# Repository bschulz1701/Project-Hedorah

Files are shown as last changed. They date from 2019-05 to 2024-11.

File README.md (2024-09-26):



# Project-Hedorah
A hardened CO2 sensing system designed for use in unusual environments 

>[!NOTE]
> Manufacture and assembly information is discussed in detail in [DFM_-_Hedorah-NDIR](https://github.com/GEMS-sensing/DFM_-_Hedorah-NDIR)

# Repo Roadmap
#### [Documents](Documents/)

General document and image storage for repo and README

#### [Hardware](Hardware/)

Current board files (Eagle), and other electrical design documents

#### [Mechanical](Mechanical/)

Mechanical design files and assembly documents

#### [Production](Production/)

Contains the various Gerber and pick and place files required to have the Printed Circuit Boards (PCBs) manufactured or populated 

#### [Software](Software/)

The software associated with the piece of hardware, this is usually diagnostic software used for verifying or investigating the hardware

<!-- #### [Testing](Testing/)

Scripts and results from the testing process and development process. Contains more detailed information about documented issues among other testing. --> 

## Overview
* **Type:** Sensor
* **Interfaces:** I<sup>2</sup>C
<!-- * **Release Version:** v1.0 - 2021/04/14  -->

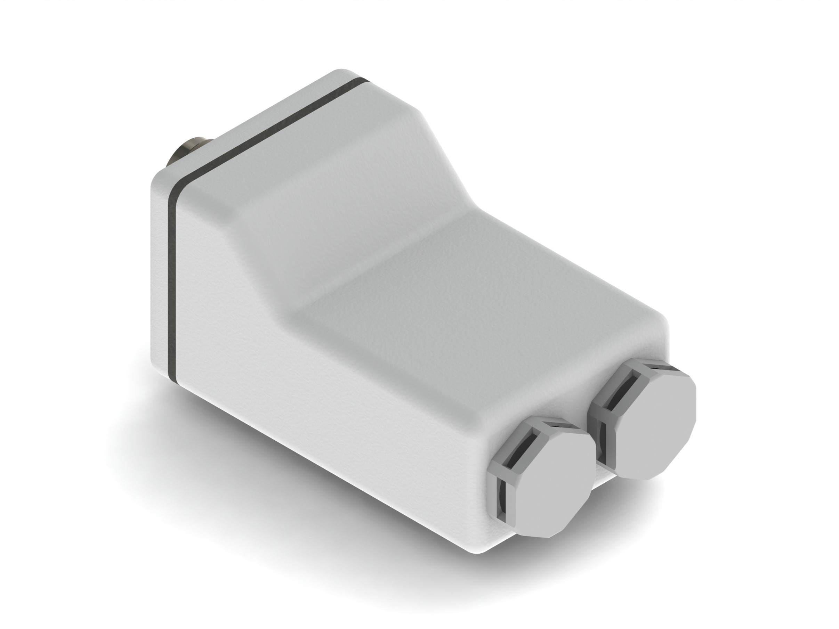
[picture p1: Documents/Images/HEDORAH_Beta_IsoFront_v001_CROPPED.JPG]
Hedroah Mrk 2 Enclosure Render, Isometric


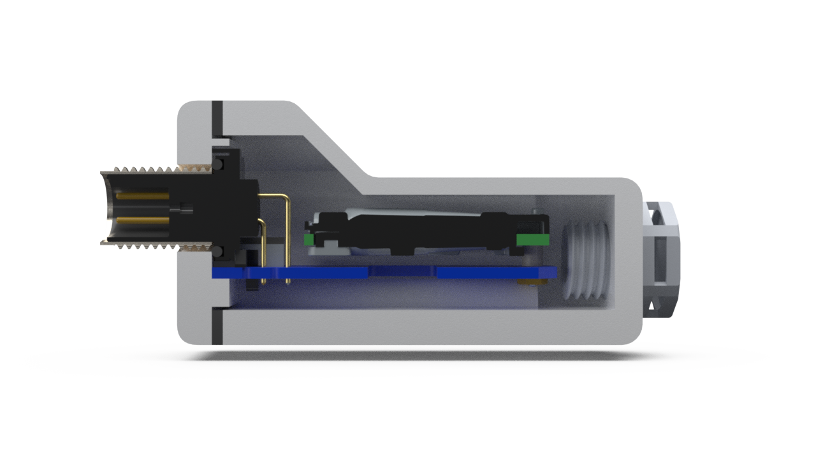
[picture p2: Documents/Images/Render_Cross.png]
Hedroah Mrk 2 Enclosure Render, Cross Section


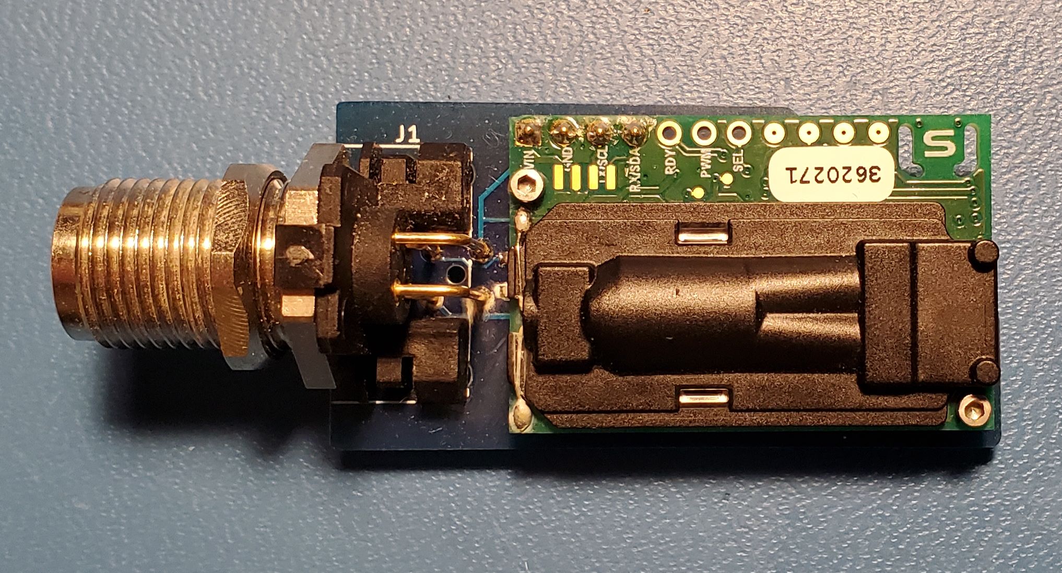
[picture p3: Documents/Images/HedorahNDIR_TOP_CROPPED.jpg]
Hedroah NDIR v1.0 - Top


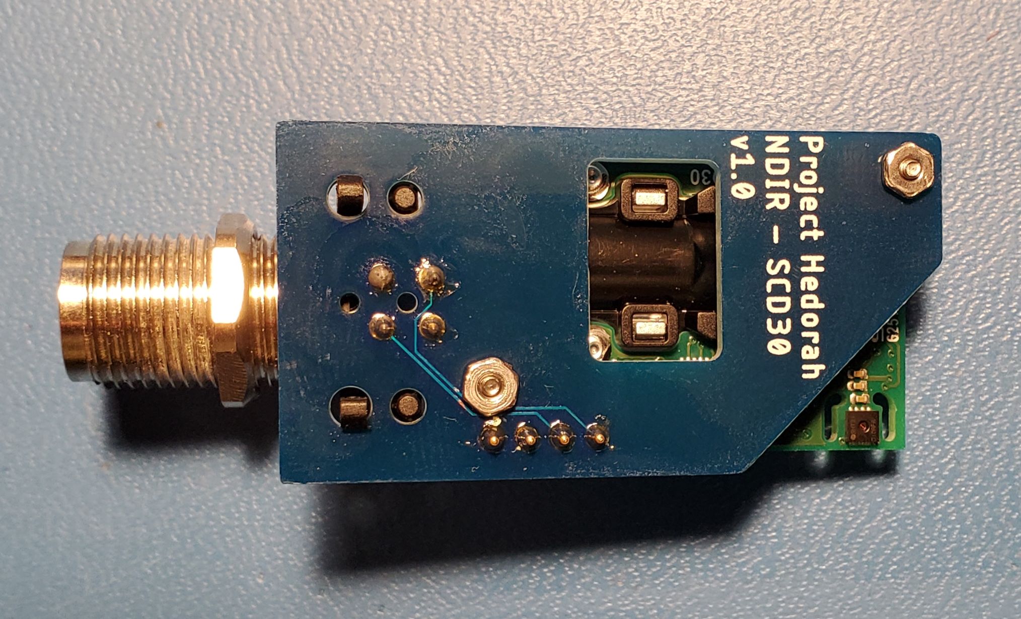
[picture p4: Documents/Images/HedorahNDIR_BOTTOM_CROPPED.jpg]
Hedroah NDIR v1.0 - Bottom


## Features
### On-Board
* Non-Dispersive InfraRed (NDIR) CO2 sensor - Sensirion SCD30
* IP68 rating (hardened sensor housing)

### Interface
* I<sup>2</sup>C data interface
* M12 circular connector 

<!-- ![Pinout](Documents/Images/Pinout.png) -->

<picture>
  <source media="(prefers-color-scheme: dark)" srcset="Documents/Images/Pinout_LIGHT.png">
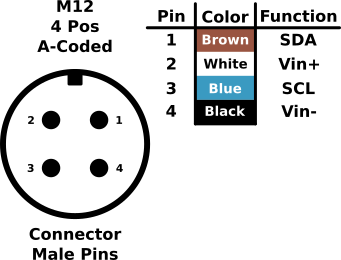
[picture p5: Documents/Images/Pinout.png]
Hedorah Connector Pinout
  
</picture>

## Specifications
#### Electrical
* **Input Voltage:** 3.3V
* **Sensor Current (Avg):** 19mA [^1]
* **Sensor Current (Max):** 75mA [^1]

[^1]: [SCD30 Datasheet](https://sensirion.com/media/documents/4EAF6AF8/61652C3C/Sensirion_CO2_Sensors_SCD30_Datasheet.pdf)

#### Sensor [^1]
**CO2**
* Range: 0 ~ 40,000 ppm CO2 
* Accuracy: &plusmn; 30 ppm + (3% Measured Value)
* Repeatability: &plusmn; 10 ppm

**Humidity**
* Range: 0 ~ 100%
* Accuracy: &plusmn; 3%
* Repeatability: 0.1%

**Temperature**
* Range: -40 ~ 70°C 
* Accuracy: &plusmn; (0.4°C + 0.023 x (Temperature [°C] - 25°C))
* Repeatability: &plusmn; 0.1°C

## Version History

**Mrk 0 - Prototype:** Breakout/development board for SGP30 eCO2 sensor

**Mrk 1 - eCO2:** Same components as Mrk 0, but arranged into a streamlined formfactor, compatable with [Haar](https://github.com/NorthernWidget-Skunkworks/Project-Haar) enclosure 

**Mrk 2 - NDIR:** Switched sensor to SCD30 NDIR sensor, moved away from Haar enclosure to custom enclosure

  * `v0.0` - Initial NDIR version, breakout only

  * `v1.0` - Added reverse polarity protection and I2C pullups

**Mrk 3 - Dual (BETA):** Dual sensor version with low and high range sensor

## Jumper Settings 

**Configuration Jumpers** [^2]
| Jumper | Purpose | Open | Closed | Default | 
| --- | --- | --- | --- | ----- |
| `JP1` | Bypass reverse polarity protection | protection enabled | protection disabled | Open |  

[^2]: Mrk 2 only

## Known Issues/Errata

#### Vent Thread Tolerance 

**Issue:** In some cases the tolerance of the thread manufacture on the [housing body](Mechanical/HEDORAH-001_-_BetaBody/HEDORAH-001_-_BetaBody_v001.stl) can be too tight. This can be seen clearly if applying the specified torque to the vents does not screw them fully down (O-Rings making contact with the housing body). 

**Workaround:** If the issue is minor, it can be corrected by applying some plastic compatible [silicone lubricant](https://www.mcmaster.com/3025K11/) to the threads of the vent before installing - take care to only apply this to the threads and not to contaminate the vent membrane. If this is not sufficient, threads can be repaired by running an [M12x1.5mm](https://www.mcmaster.com/26015A612/) hand-tap through the holes to ensure they meet specifications.

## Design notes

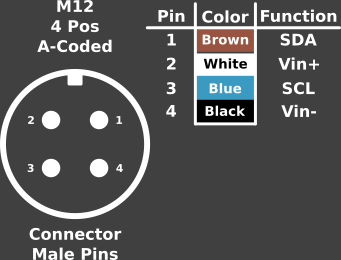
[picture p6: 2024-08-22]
Documents/Images/Pinout_LIGHT.png

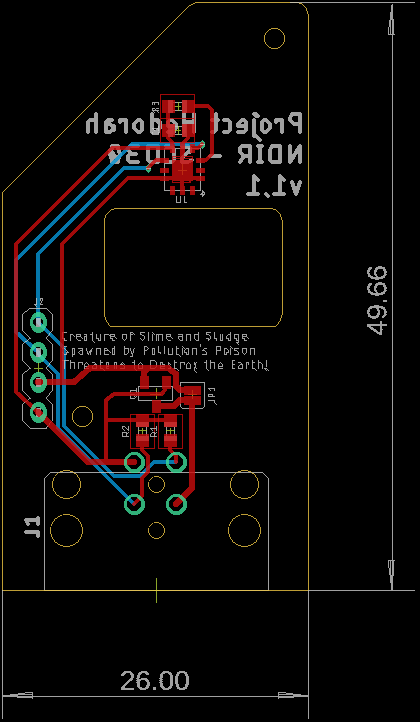
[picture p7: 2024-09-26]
Hardware/Mrk 2 - NDIR/BoardDimensions.png

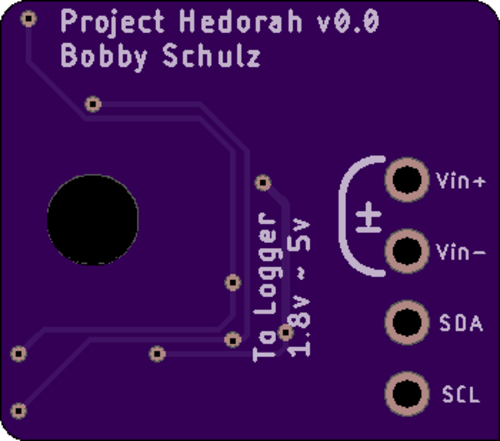
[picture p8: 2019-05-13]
Images/Bottom_Render.png

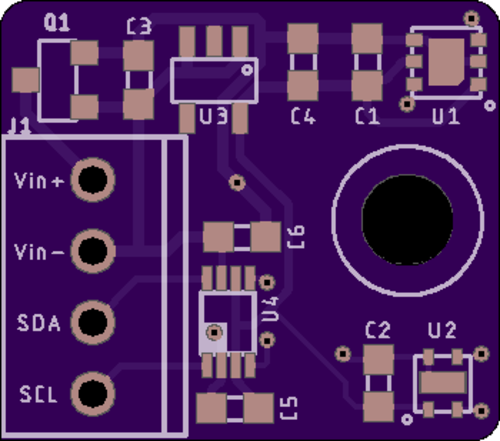
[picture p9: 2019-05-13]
Images/Top_Render.png

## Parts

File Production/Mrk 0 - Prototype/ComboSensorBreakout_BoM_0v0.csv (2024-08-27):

Qty | Value | Device | Package | Parts | Description | DIGIKEY | DISP | MF | MOUSER | MPN | VALUE
1 |  | MOUNTING_HOLE4_NP | 4_40 | H1 | Genaric Mechanical Mounting Hole | DNP |  | N/A |  | DNP
4 | 0.1uF | C-EU0.1UFC0603 | C0603 | C1, C2, C5, C6 | CAPACITOR, European symbol | 490-6051-1-ND |  | Murata |  | GCM188R71E104KA57D
2 | 1uF | C-EU1UFC0603 | C0603 | C3, C4 | CAPACITOR, European symbol | 490-10479-1-ND |  | Murata |  | GRM188R61C105KA12D
1 | CONN_42.54_SCREW | CONN_42.54_SCREW | 1X04_SCREW | J1 | Genaric 4 terminal header | ED10563-ND |  | On Shore |  | OSTVN04A150
1 | DMG3404 | MOSFET-NCH-DMG3404L | SOT23-3 | Q1 | N-channel MOSFETs | DMG3404L-7DICT-ND |  | Diodes Incorporated |  | DMG3404L-7 | DMG3404
1 | SHTC3DFN | SHTC3DFN | DFN_4_2X2 | U2 | SHTCx - Digital Humidity and Temperature Sensor | 1649-1100-1-ND | SHTC3 | Sensirion |  | SHTC3
1 | SPG30 | SPG30 | DFN_6_2.5X2.5 | U1 | SGP30 - Multi-pixel Gas Sensor (TVOC, CO2EQ) | 1649-1084-1-ND |  | Sensirion |  | SGP30-2.5K
1 | TPS7A0518DBV | TPS7A0518DBV | SOT23-5 | U3 | TPS7A05* - Ultra Low Power Low Dropout Linear Regulator | 296-50251-1-ND |  | TI | 595-TPS7A0518PDBVR | TPS7A0518PDBVR
1 | TXS0102DCU | TXS0102DCU | DCU_(R-PDSO-G8) | U4 | TXS0102 - 2 Channel Bidirectional Voltage Level Translator | 296-21931-1-ND |  | TI |  | TXS0102DCUR

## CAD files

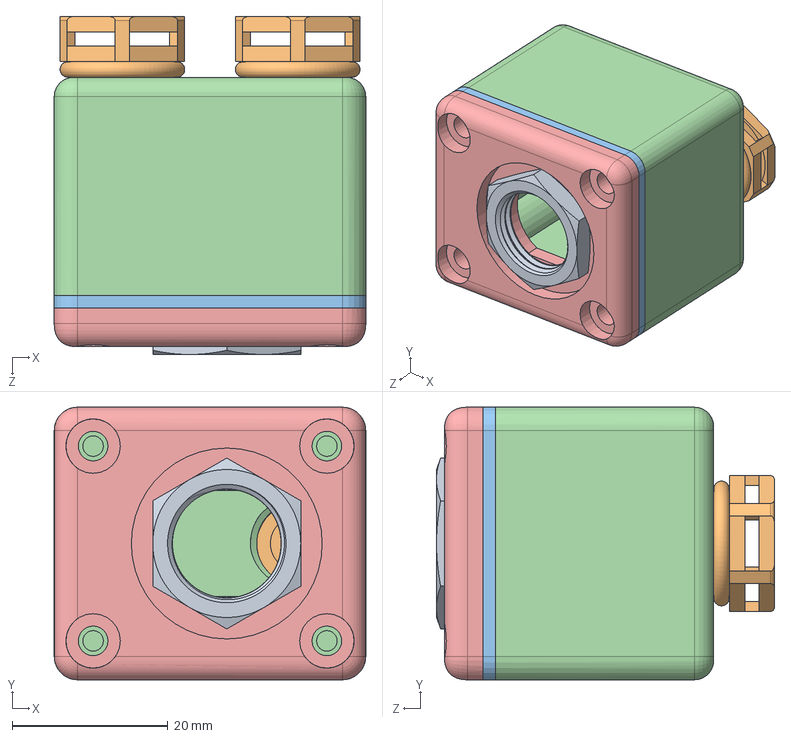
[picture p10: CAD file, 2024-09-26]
Mechanical/Mrk 3 Body Assembly/VertFull.SLDASM
40.0 x 35.0 x 43.4 mm
HEDORAH-004_-_VertLid_v000
HEDORAH-005_-_VertBody-v000
HEDORAH-003_-_BetaGasket_v001
M12_Vent_wMembrane x 2
7513K142_PG-9 304 Stainless Steel Locknut for Metal Medium- and Thick-Wall Steel Conduit

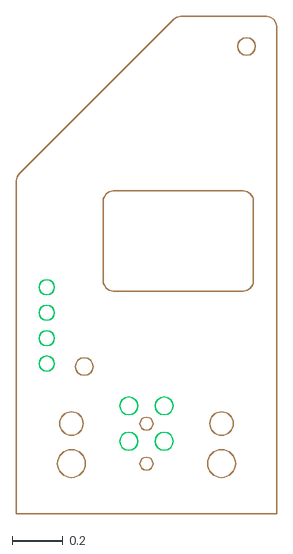
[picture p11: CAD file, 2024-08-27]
Hardware/Mrk 2 - NDIR/NDIR_SensorInterface_AllHoles.dxf
1.02 x 1.96

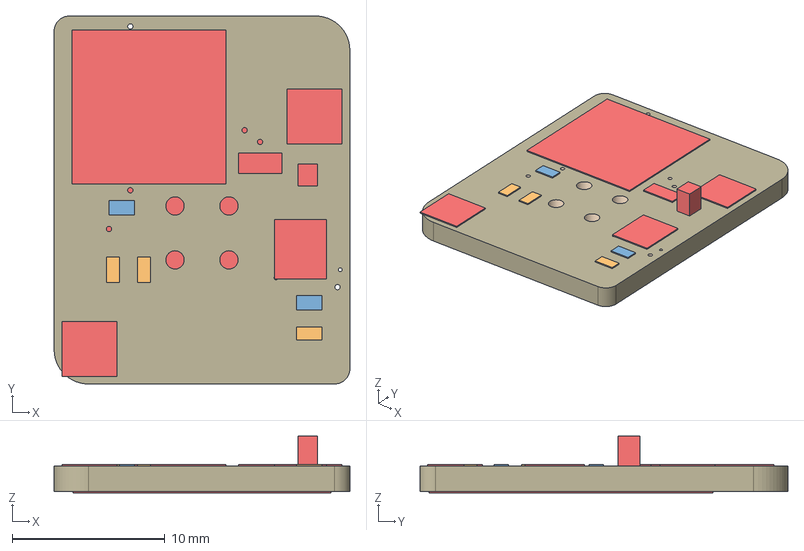
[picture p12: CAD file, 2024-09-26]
Hardware/Mrk 3 - Dual SMD/VertMount.step
19.4 x 24.1 x 3.73 mm
Board
CONN_I2C_SENSOR_BOARD_MOUNT_TH
DMG3404
JUMPER-SMT_2_NO_SILK
DNP x 3
STC31
0.1uF x 2
SCD41

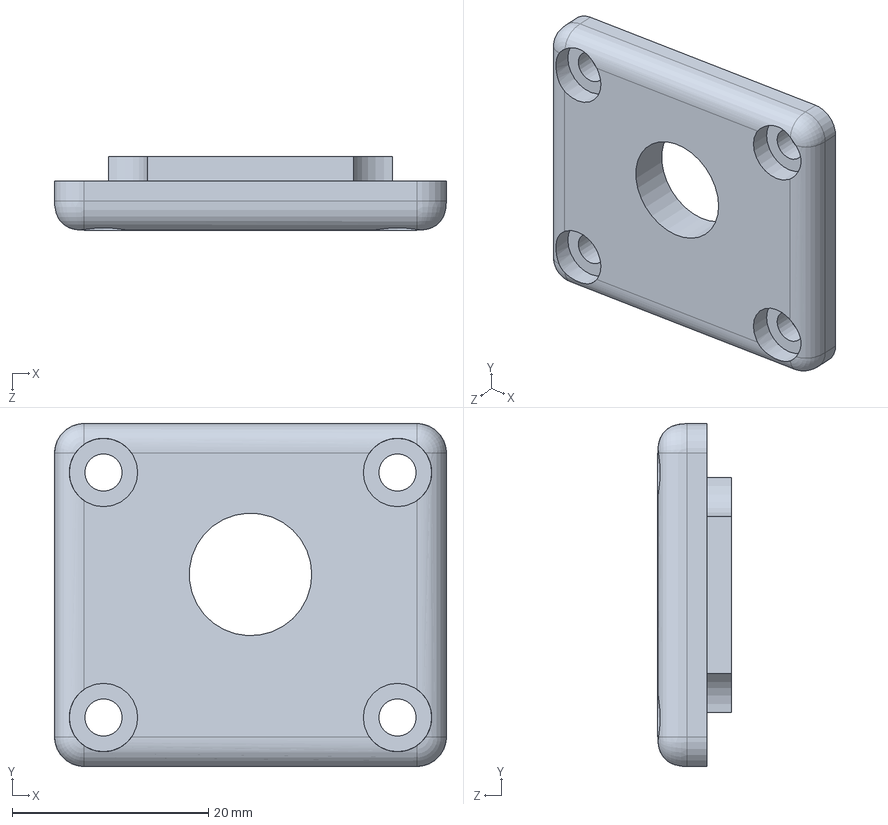
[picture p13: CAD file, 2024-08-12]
Mechanical/HEDORAH-002_-_BetaLid/HEDORAH-002_-_BetaLid_v000.SLDPRT
40.0 x 35.0 x 7.50 mm

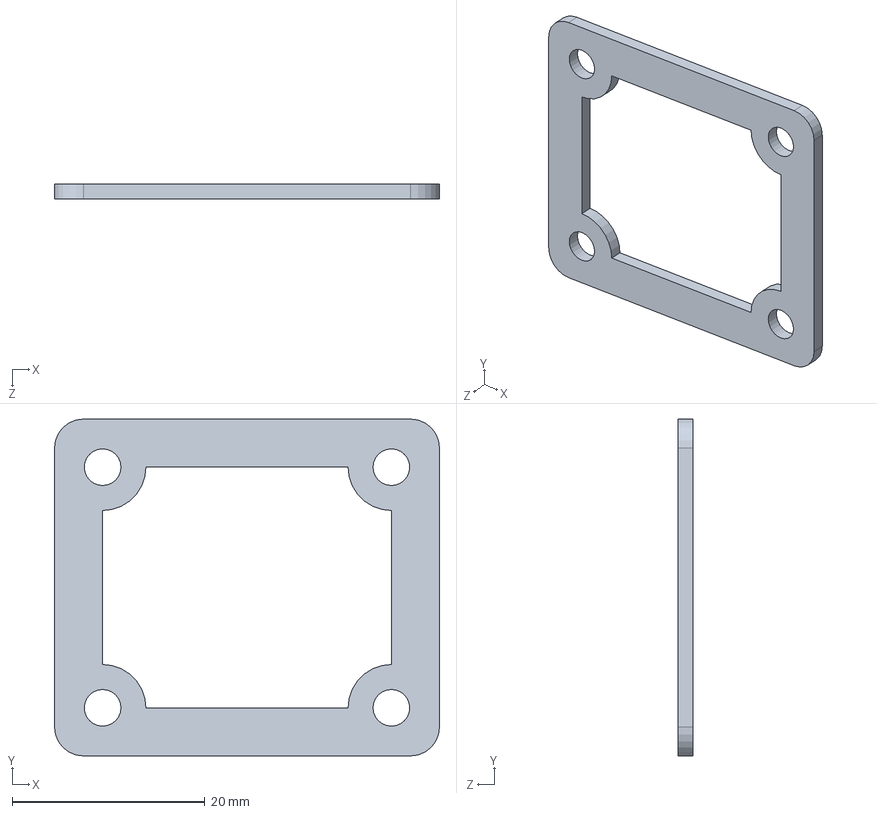
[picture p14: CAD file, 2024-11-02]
Mechanical/HEDORAH-003_-_BetaGasket/HEDORAH-003_-_BetaGasket_v001.SLDPRT
40.0 x 35.0 x 1.59 mm

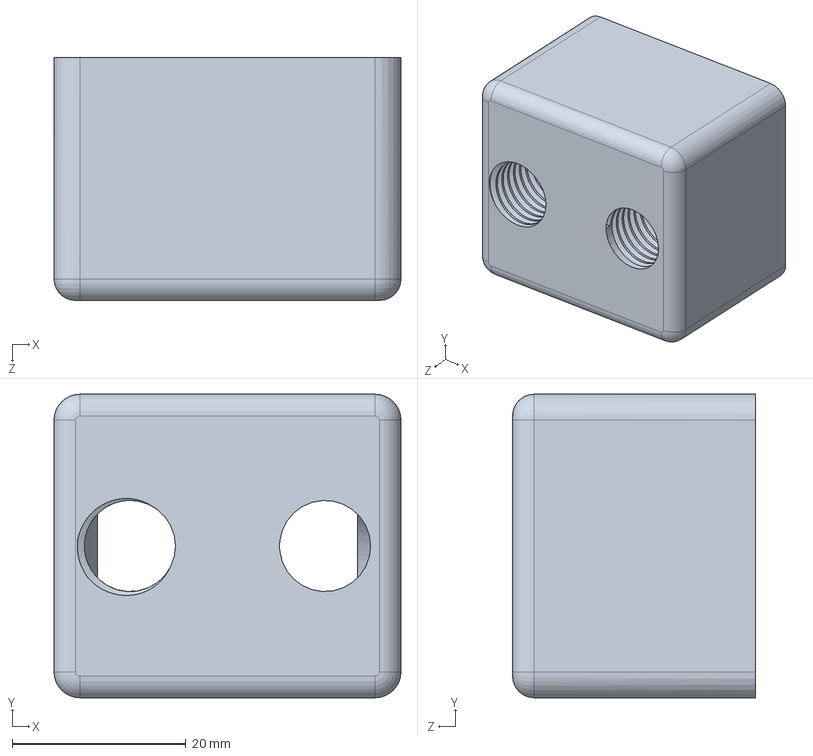
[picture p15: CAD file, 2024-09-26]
Mechanical/HEDORAH-005_-_VertBody/HEDORAH-005_-_VertBody-v000.SLDPRT
40.0 x 35.0 x 28.0 mm

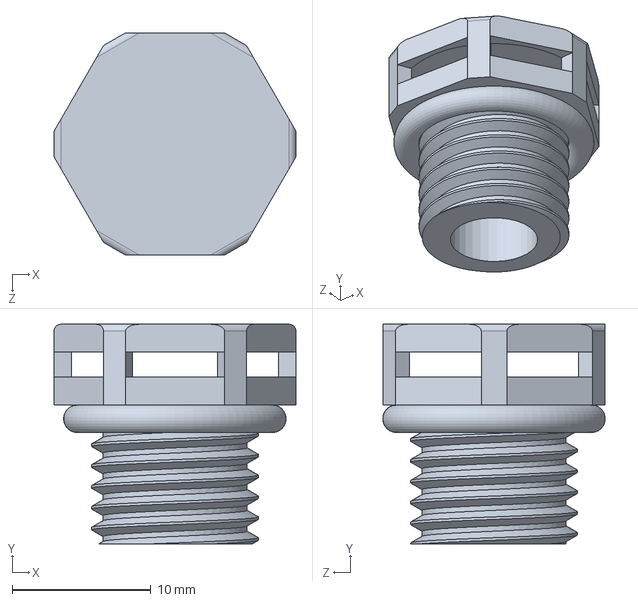
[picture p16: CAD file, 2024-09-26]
Mechanical/Mrk 3 Body Assembly/M12_Vent_wMembrane.SLDPRT
17.4 x 15.8 x 16.0 mm

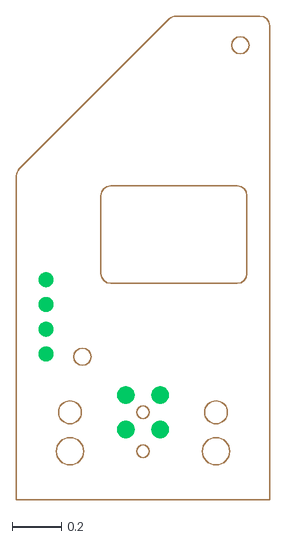
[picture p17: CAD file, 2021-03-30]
Hardware/Mrk 2 - NDIR/NDIR_SensorInterface.dxf
1.02 x 1.96

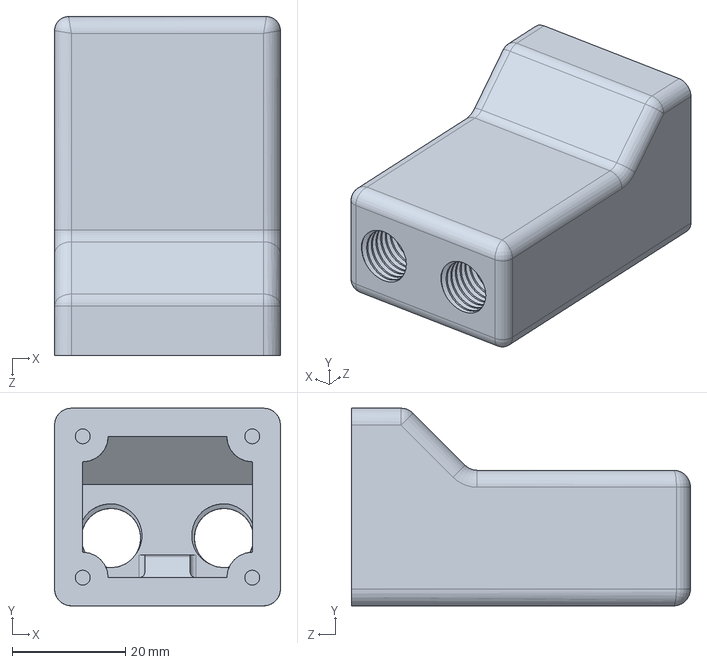
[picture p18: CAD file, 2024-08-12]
Mechanical/HEDORAH-001_-_BetaBody/HEDORAH-001_-_BetaBody_v001.SLDPRT
40.0 x 35.0 x 60.0 mm

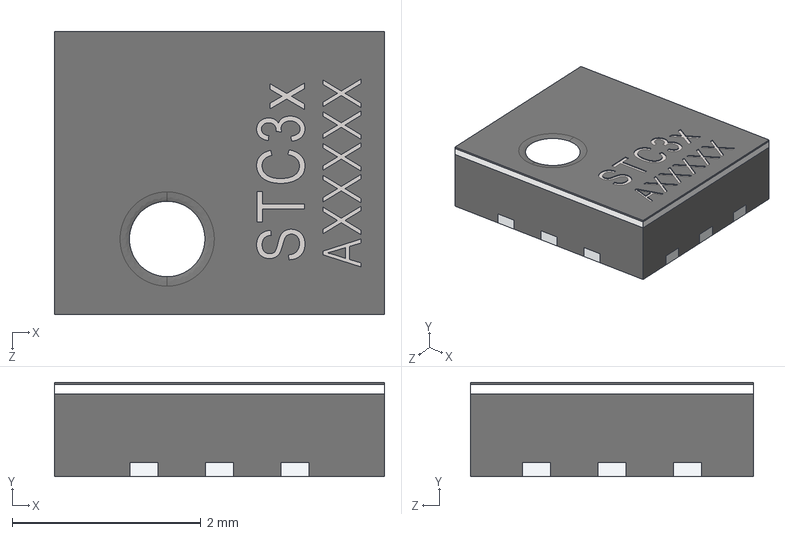
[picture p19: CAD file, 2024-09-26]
Mechanical/Mrk 3 Body Assembly/STC31_STEP_file.step
3.50 x 1.00 x 3.00 mm

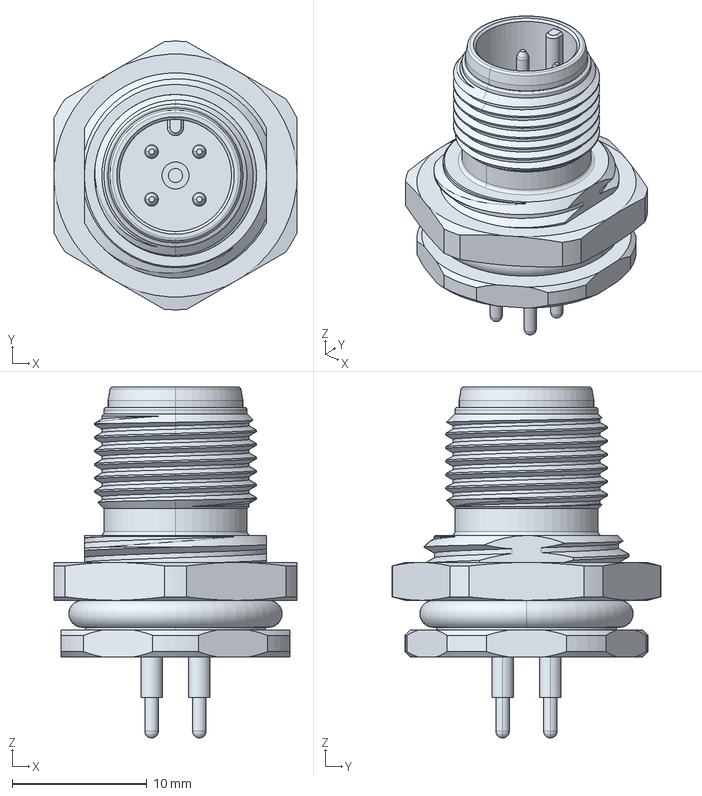
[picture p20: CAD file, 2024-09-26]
Mechanical/Mrk 3 Body Assembly/c-t4140012041-000-b-3d.stp
18.0 x 19.9 x 26.0 mm

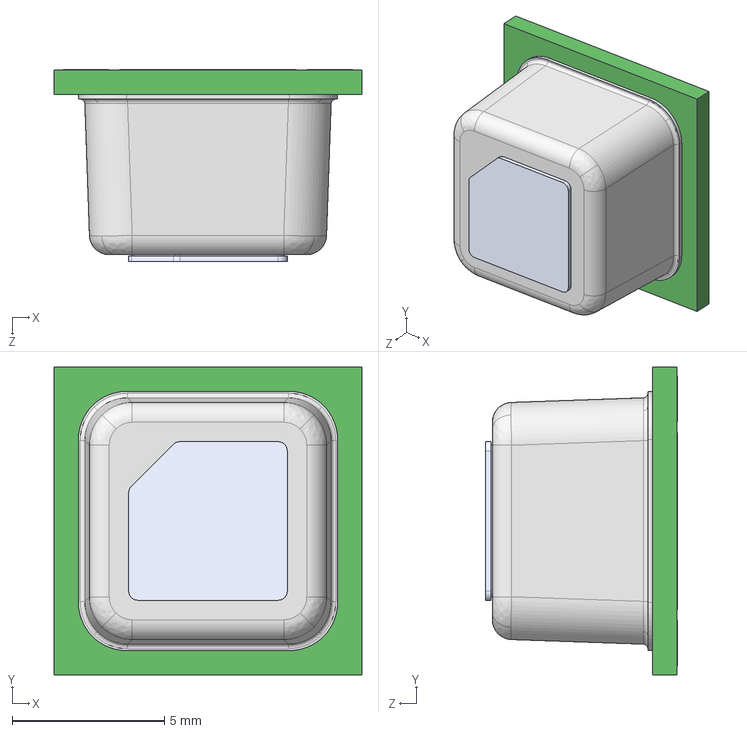
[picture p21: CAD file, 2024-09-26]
Mechanical/Mrk 3 Body Assembly/Sensirion_CO2_Sensors_SCD4x_STEP_file.step
10.1 x 10.1 x 6.31 mm

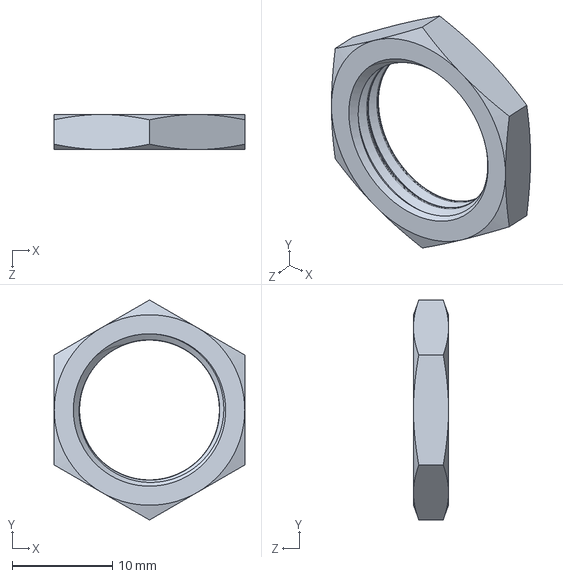
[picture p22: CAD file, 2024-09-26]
Mechanical/Mrk 3 Body Assembly/7513K142_PG-9 304 Stainless Steel Locknut for Metal Medium- and Thick-Wall Steel Conduit.SLDPRT
19.0 x 21.9 x 3.50 mm

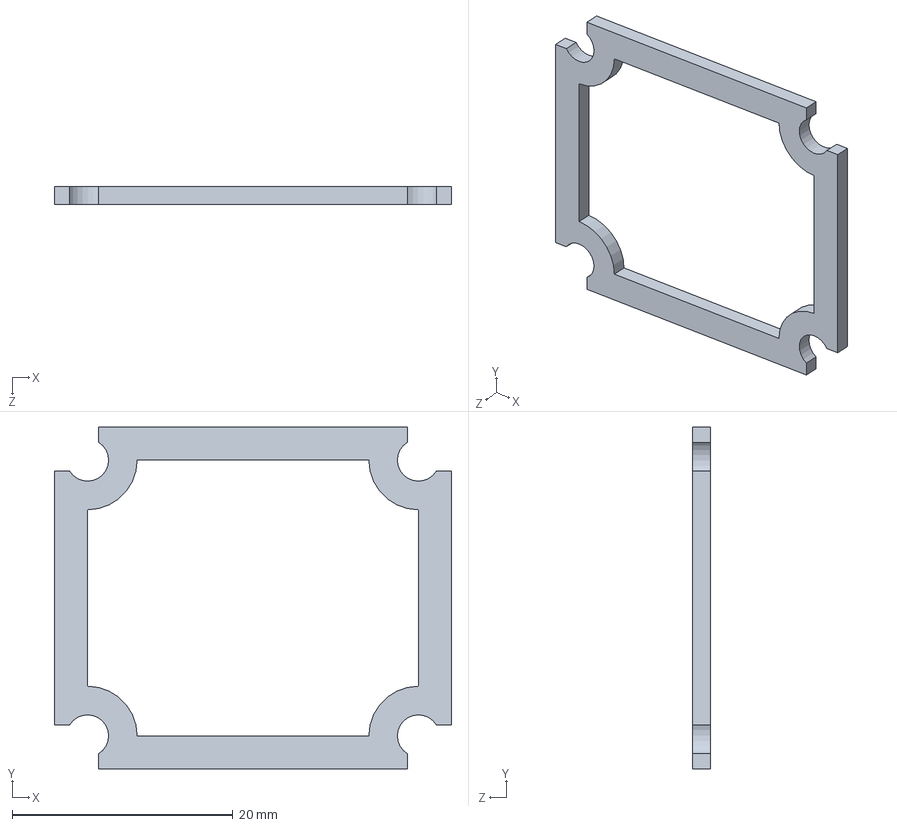
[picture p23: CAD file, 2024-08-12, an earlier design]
Mechanical/HEDORAH-003_-_BetaGasket/HEDORAH-003_-_BetaGasket_v000.SLDPRT
36.0 x 31.0 x 1.59 mm

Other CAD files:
Mechanical/Mrk 3 Body Assembly/VertMount.SLDASM
Mechanical/HEDORAH-004_-_VertLid/HEDORAH-004_-_VertLid_v000.SLDPRT
Mechanical/HEDORAH-001_-_BetaBody/HEDORAH-001_-_BetaBody_v000.SLDPRT
Mechanical/HEDORAH-001_-_BetaBody/HEDORAH-001_-_BetaBody_v000.STL
Mechanical/HEDORAH-001_-_BetaBody/HEDORAH-001_-_BetaBody_v001.STL
Mechanical/HEDORAH-002_-_BetaLid/HEDORAH-002_-_BetaLid_v000.STL
Mechanical/HEDORAH-003_-_BetaGasket/HEDORAH-003_-_BetaGasket_v000.DXF
Mechanical/HEDORAH-003_-_BetaGasket/HEDORAH-003_-_BetaGasket_v001.DXF
Mechanical/HEDORAH-004_-_VertLid/HEDORAH-004_-_VertLid_v000.STL
Mechanical/HEDORAH-005_-_VertBody/HEDORAH-005_-_VertBody-v000.STL
Mechanical/Mrk 3 Body Assembly/STC31_STEP_file.SLDPRT
Mechanical/Mrk 3 Body Assembly/Sensirion_CO2_Sensors_SCD4x_STEP_file.SLDPRT
Mechanical/Mrk 3 Body Assembly/VertMount.SLDPRT
Mechanical/Mrk 3 Body Assembly/c-t4140012041-000-b-3d.SLDPRT

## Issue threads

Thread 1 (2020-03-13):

Fix Silkscreen

bschulz1701, 2020-03-13:
Silkscreen is mis-labeled, `Vin+` and `Vin-` are reversed on both top and bottom

Closed 2020-03-13.

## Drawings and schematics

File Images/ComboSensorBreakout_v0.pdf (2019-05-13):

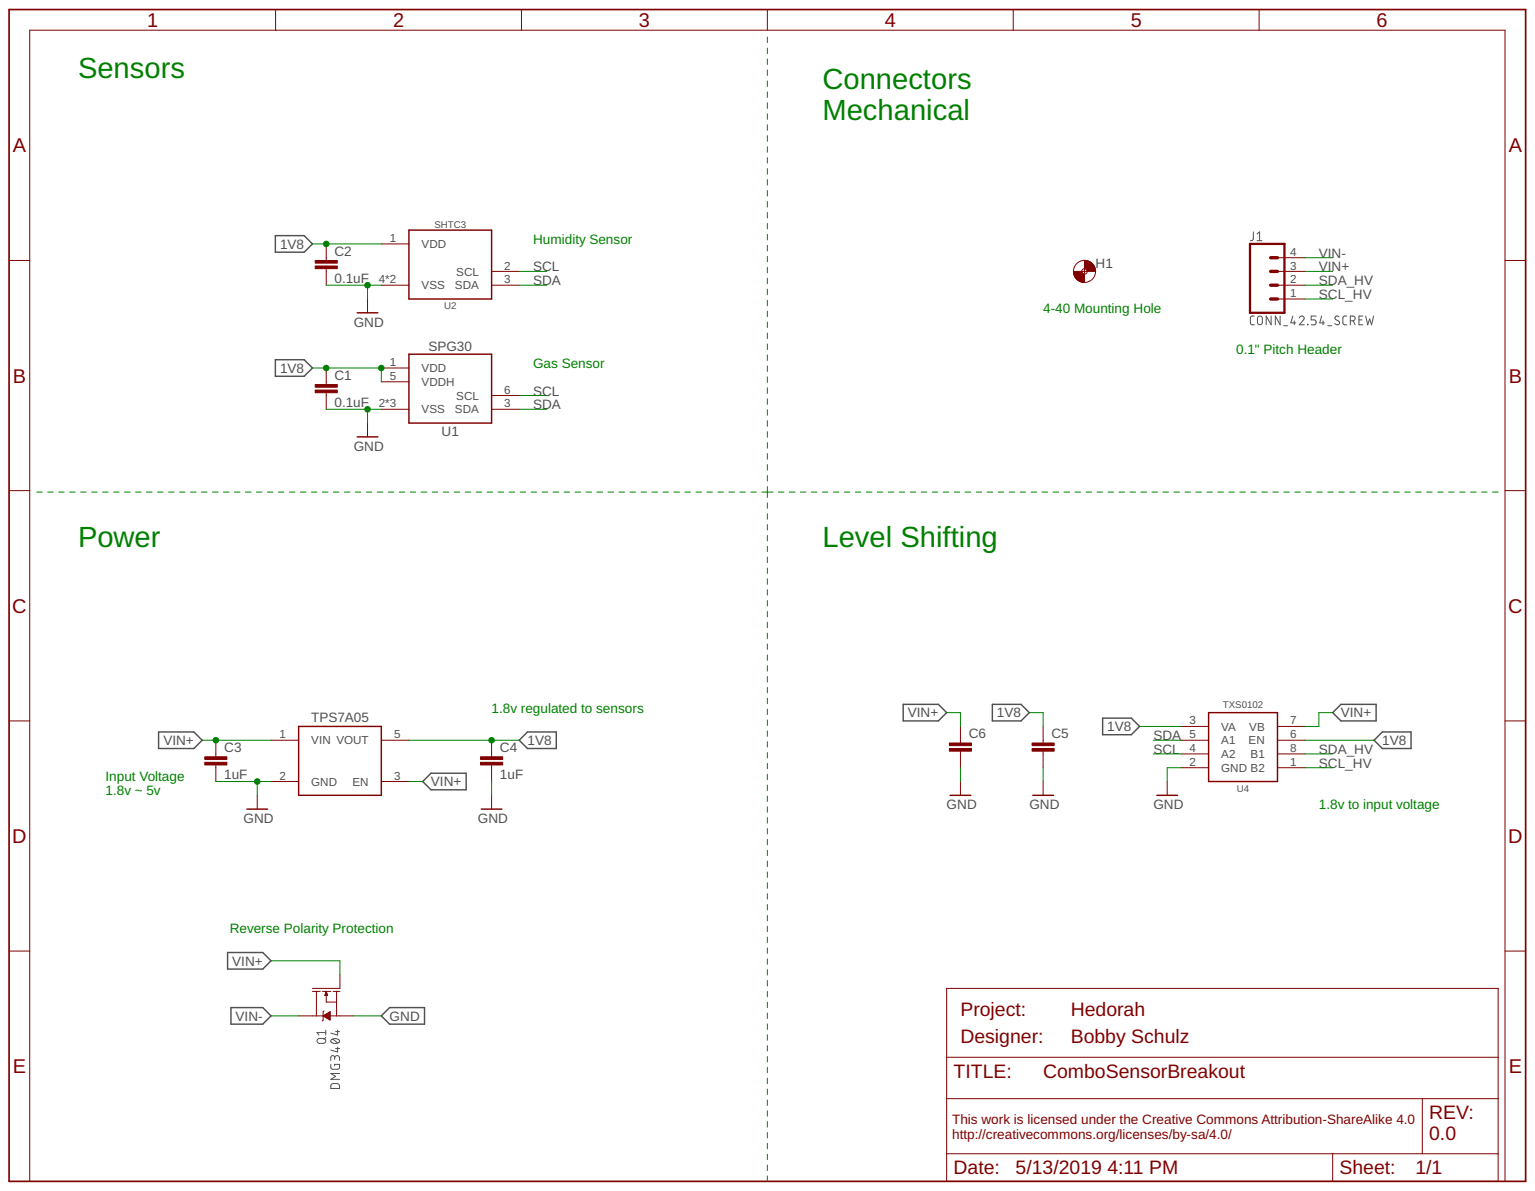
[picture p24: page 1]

This work is licensed under the Creative Commons Attribution-ShareAlike 4.0 http://creativecommons.org/licenses/by-sa/4.0/ | REV: 0.0

Date: 5/13/2019 4:11 PM | Sheet: 1/1

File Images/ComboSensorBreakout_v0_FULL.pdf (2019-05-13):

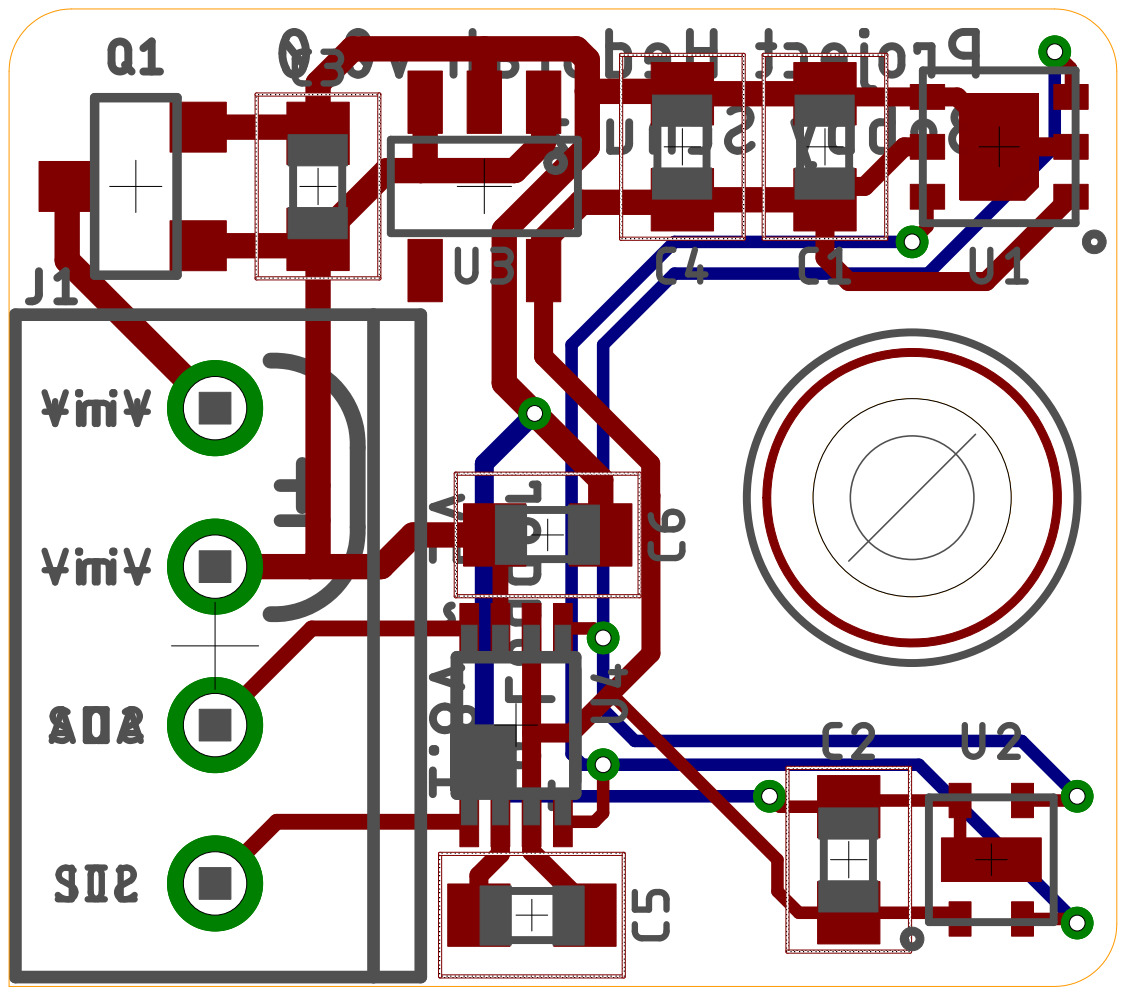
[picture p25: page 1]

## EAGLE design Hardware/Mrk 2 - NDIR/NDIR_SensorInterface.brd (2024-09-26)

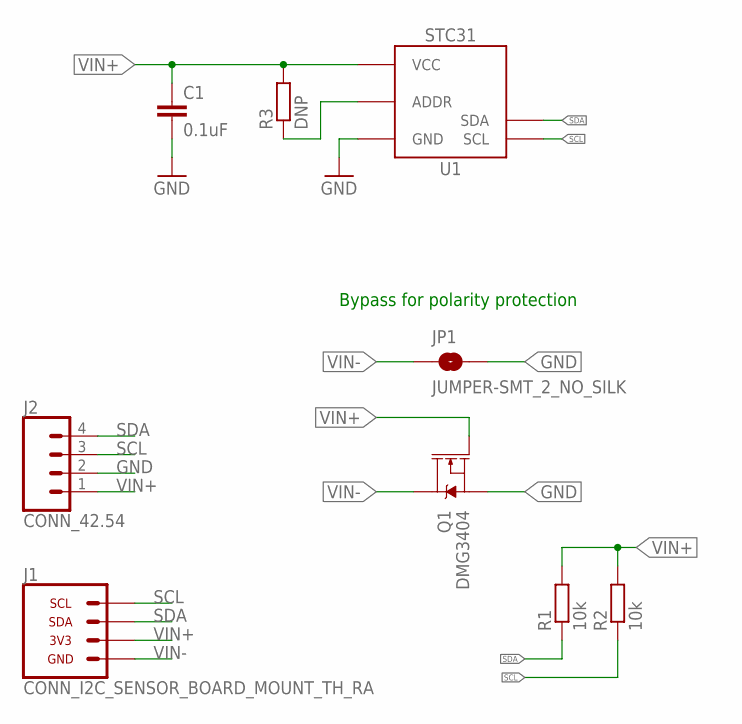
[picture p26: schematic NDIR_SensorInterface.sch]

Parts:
C1: 0.1uF; C0603
J1: CONN_I2C_SENSOR_BOARD_MOUNT_TH_RA; CONEC_43-01204
J2: CONN_42.54; 1X04; MPN 800-10-004-10-002000; DIGIKEY ED7564-04-ND
JP1: JUMPER-SMT_2_NO_SILK; SMT-JUMPER_2_NO_SILK
Q1: DMG3404; SOT23-3
R1, R2: 10k; R0603
R3: DNP; R0603
U1: STC31

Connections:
GND: C1.2, J2.2, JP1.2, Q1.2 (S), U1.1 (GND), U1.5 (GND), U1.9 (GND), U1.11 (GND), U1.EP (GND)
unnamed: R3.1, U1.3 (ADDR)
SCL: J1.3 (SCL), J2.3, R2.1, U1.4 (SCL)
SDA: J1.1 (SDA), J2.4, R1.1, U1.7 (SDA)
VIN+: C1.1, J1.2 (3V3), J2.1, Q1.1 (G), R1.2, R2.2, R3.2, U1.6 (VCC)
VIN-: J1.4 (GND), JP1.1, Q1.3 (D)

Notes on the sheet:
Bypass for polarity protection

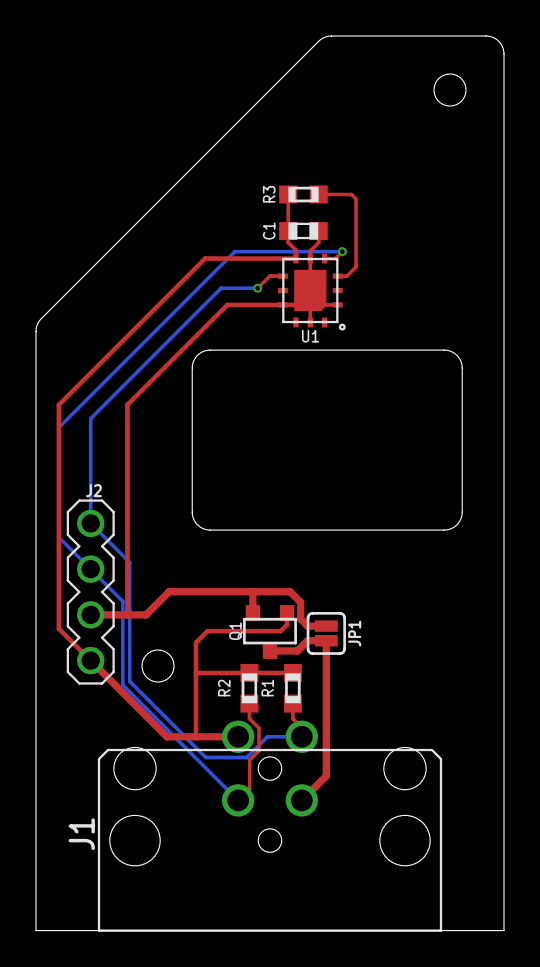
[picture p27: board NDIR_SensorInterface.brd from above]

Board: 2 copper layers, 26.0 x 49.7 mm, 9 parts (0 on the bottom side), 6 nets.

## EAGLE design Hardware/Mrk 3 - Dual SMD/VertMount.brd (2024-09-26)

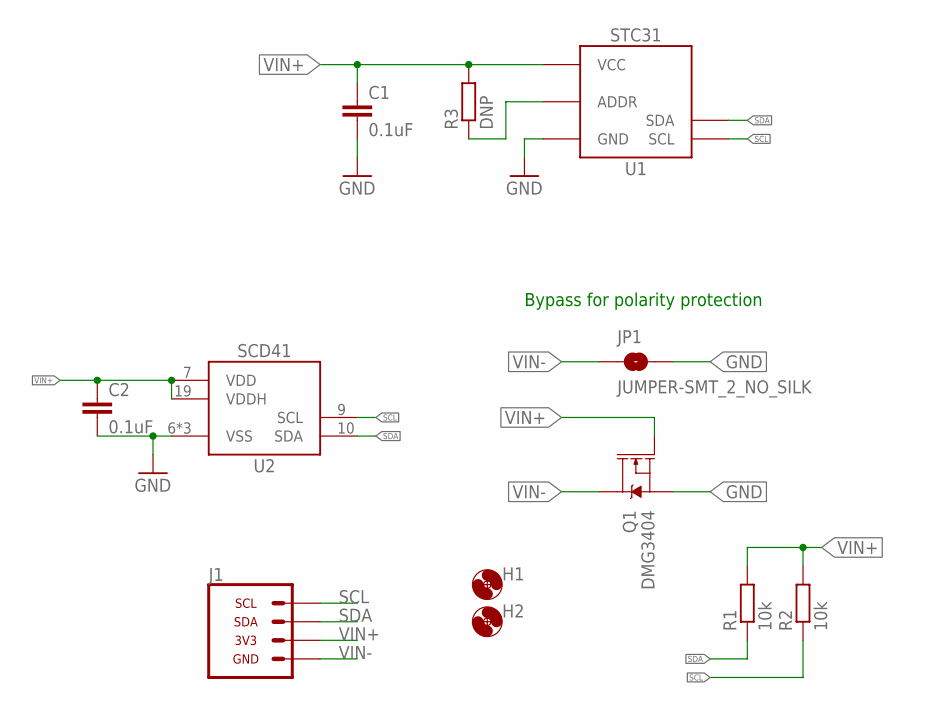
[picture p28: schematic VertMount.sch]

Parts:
C1, C2: 0.1uF; C0603
H1, H2: MOUNTING_HOLE1_NP; 1_72
J1: CONN_I2C_SENSOR_BOARD_MOUNT_TH; 1X04_M12_TE_T41400
JP1: JUMPER-SMT_2_NO_SILK; SMT-JUMPER_2_NO_SILK
Q1: DMG3404; SOT23-3
R1, R2: 10k; R0603
R3: DNP; R0603
U1: STC31
U2: SCD41; SCD4X

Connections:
GND: C1.2, C2.2, JP1.2, Q1.2 (S), U1.1 (GND), U1.5 (GND), U1.9 (GND), U1.11 (GND), U1.EP (GND), U2.6 (VSS), U2.20 (VSS), U2.EP (VSS)
unnamed: R3.1, U1.3 (ADDR)
SCL: J1.3 (SCL), R2.1, U1.4 (SCL), U2.9 (SCL)
SDA: J1.1 (SDA), R1.1, U1.7 (SDA), U2.10 (SDA)
VIN+: C1.1, C2.1, J1.2 (3V3), Q1.1 (G), R1.2, R2.2, R3.2, U1.6 (VCC), U2.7 (VDD), U2.19 (VDDH)
VIN-: J1.4 (GND), JP1.1, Q1.3 (D)

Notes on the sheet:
Bypass for polarity protection

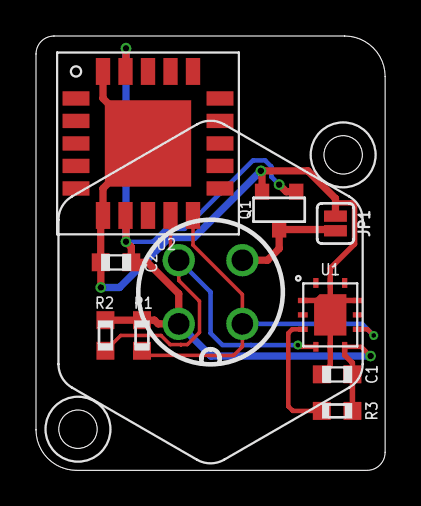
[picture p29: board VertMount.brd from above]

Board: 2 copper layers, 19.4 x 24.1 mm, 12 parts (1 on the bottom side), 6 nets.

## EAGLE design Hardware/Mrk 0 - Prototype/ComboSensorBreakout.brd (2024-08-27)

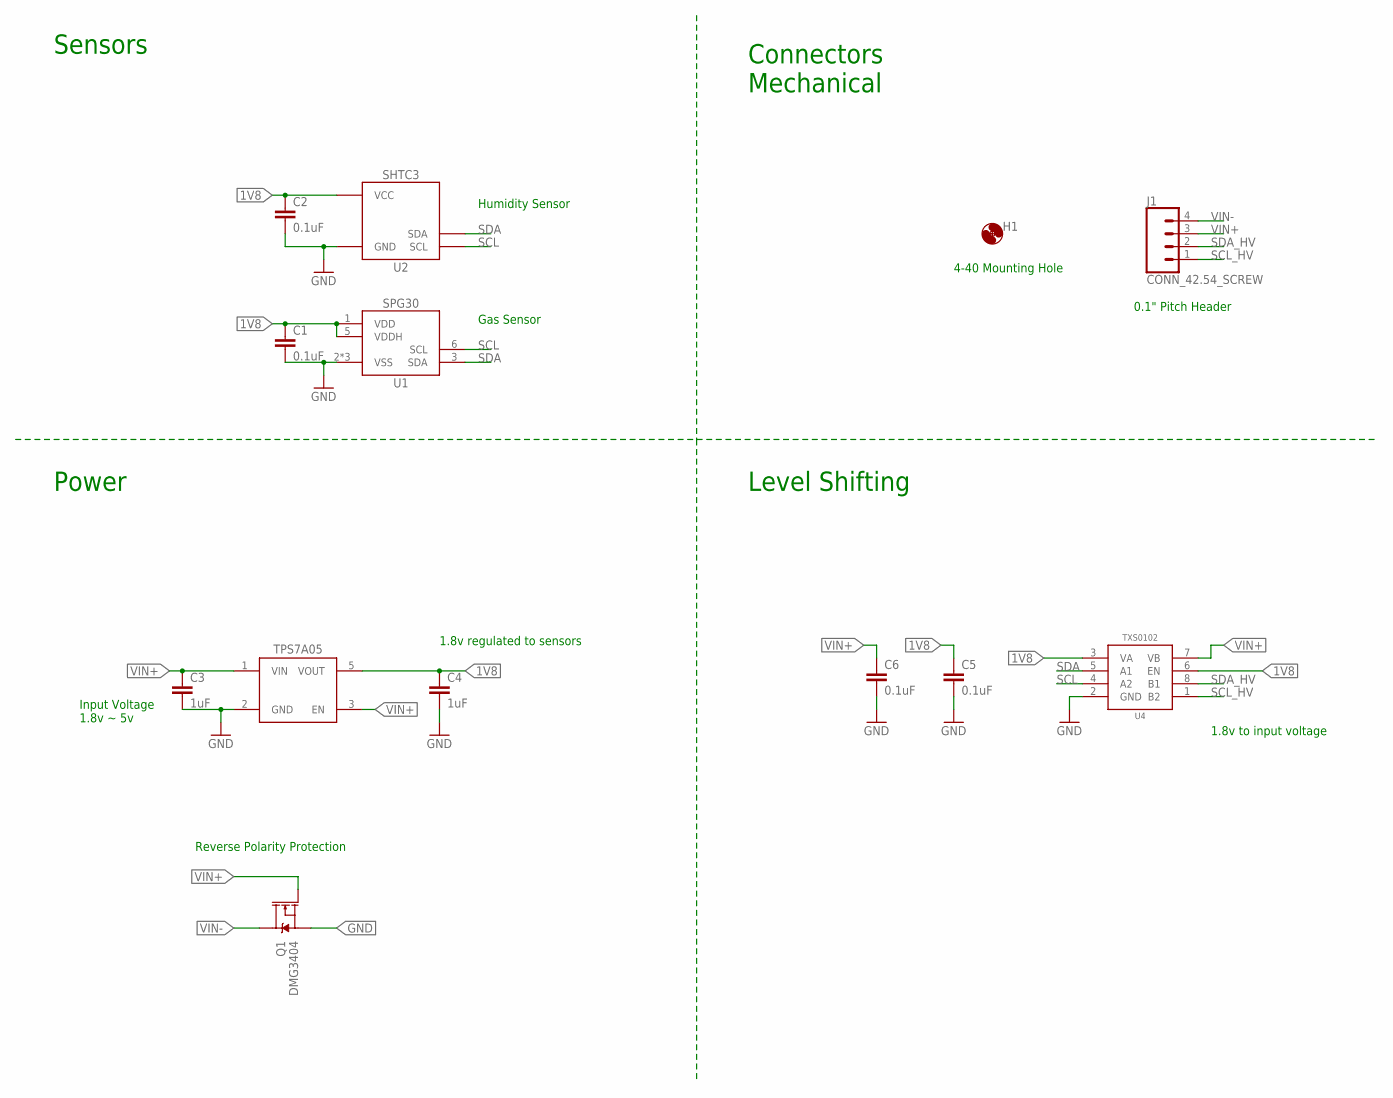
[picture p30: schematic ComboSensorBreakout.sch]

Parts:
C1, C2, C5, C6: 0.1uF; C0603
C3, C4: 1uF; C0603
H1: MOUNTING_HOLE4_NP; 4_40; MPN DNP; DIGIKEY DNP
J1: CONN_42.54_SCREW; 1X04_SCREW
Q1: DMG3404; SOT23-3
U1: SPG30; DFN_6_2.5X2.5
U2: SHTC3DFN; DFN_4_2X2
U3: TPS7A0518DBV; SOT23-5; DIGIKEY 296-50251-1-ND
U4: TXS0102DCU; DCU_(R-PDSO-G8)

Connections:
1V8: C1.1, C2.1, C4.1, C5.1, U1.1 (VDD), U1.5 (VDDH), U2.1 (VCC), U3.5 (VOUT), U4.3 (VA), U4.6 (EN)
GND: C1.2, C2.2, C3.2, C4.2, C5.2, C6.2, Q1.2 (S), U1.2 (VSS), U1.4 (VSS), U1.EP (VSS), U2.4 (GND), U2.EP (GND), U3.2 (GND), U4.2 (GND)
SCL: U1.6 (SCL), U2.2 (SCL), U4.4 (A2)
SCL_HV: J1.1, U4.1 (B2)
SDA: U1.3 (SDA), U2.3 (SDA), U4.5 (A1)
SDA_HV: J1.2, U4.8 (B1)
VIN+: C3.1, C6.1, J1.3, Q1.1 (G), U3.1 (VIN), U3.3 (EN), U4.7 (VB)
VIN-: J1.4, Q1.3 (D)

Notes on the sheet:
Sensors
Connectors Mechanical
Level Shifting
Power
Input Voltage 1.8v ~ 5v
1.8v regulated to sensors
Gas Sensor
Humidity Sensor
1.8v to input voltage
4-40 Mounting Hole
0.1" Pitch Header
Reverse Polarity Protection

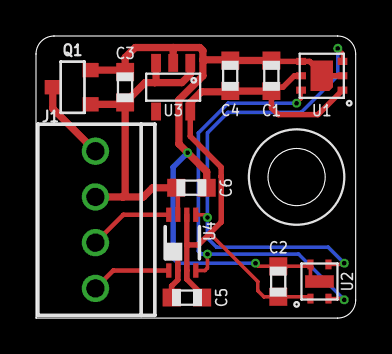
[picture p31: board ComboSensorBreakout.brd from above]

Board: 2 copper layers, 17.8 x 15.7 mm, 13 parts (0 on the bottom side), 8 nets.

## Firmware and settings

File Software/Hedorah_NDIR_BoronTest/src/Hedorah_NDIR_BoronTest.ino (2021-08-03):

/*
  Reading CO2, humidity and temperature from the SCD30
  By: Nathan Seidle
  SparkFun Electronics
  Date: May 22nd, 2018
  License: MIT. See license file for more information but you can
  basically do whatever you want with this code.

  Feel like supporting open source hardware?
  Buy a board from SparkFun! https://www.sparkfun.com/products/15112

  This example prints the current CO2 level, relative humidity, and temperature in C.

  Hardware Connections:
  Attach RedBoard to computer using a USB cable.
  Connect SCD30 to RedBoard using Qwiic cable.
  Open Serial Monitor at 115200 baud.
*/

// #include <Wire.h>

#include "SparkFun_SCD30_Arduino_Library.h" //Click here to get the library: http://librarymanager/All#SparkFun_SCD30
SCD30 airSensor;

namespace Pins { //Use for Boron
	constexpr uint16_t WD_HOLD  = 7;
	constexpr uint16_t EXT_EN   = 8;
	constexpr uint16_t SD_EN    = 9;
	constexpr uint16_t SD_CS    = 14;
	constexpr uint16_t SDA_CTRL = 2;
	constexpr uint16_t TIP      = 15;
	constexpr uint16_t GPIOXA 	= 16;
	constexpr uint16_t Clock_INT 	= 2;
  constexpr uint16_t Port1D 	= D6;
	constexpr uint16_t Port2D 	= D5;
	constexpr uint16_t Port3D  	= D4;
	constexpr uint16_t Port1A 	= A2;
	constexpr uint16_t Port2A 	= A1;
	constexpr uint16_t Port3A 	= A0;
}

SYSTEM_MODE(MANUAL)
SYSTEM_THREAD(DISABLED)

void setup()
{
  pinMode(Pins::EXT_EN, OUTPUT);
	digitalWrite(Pins::EXT_EN, HIGH); //Turn on external power 
	pinMode(Pins::SDA_CTRL, OUTPUT);
	digitalWrite(Pins::SDA_CTRL, HIGH); //Turn on internal SDA

  Serial.begin(115200);
  delay(1000); //DEBUG!
  Serial.println("SCD30 Example");
  Wire.begin();

  if (airSensor.begin() == false)
  {
    Serial.println("Air sensor not detected. Please check wiring. Freezing...");
    while (1)
      ;
  }

  //The SCD30 has data ready every two seconds
}

void loop()
{
  if (airSensor.dataAvailable())
  {
    Serial.print("co2(ppm):");
    Serial.print(airSensor.getCO2());

    Serial.print(" temp(C):");
    Serial.print(airSensor.getTemperature(), 1);

    Serial.print(" humidity(%):");
    Serial.print(airSensor.getHumidity(), 1);

    Serial.println();
  }
  else
    Serial.println("Waiting for new data");

  delay(500);
}

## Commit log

2019-05-13 Combo sensor v0 ready for external review
    Completed initial design and documentation for combo sensor v0.0
    [ComboSensorBreakout.brd, ComboSensorBreakout.sch]
2019-05-13 Added dimensions to board document
    [ComboSensorBreakout.brd]
2020-02-22 Generated x274 gerber files
2020-03-13 Updated silk screen (fixed issue #1)
    Switched silk screen labels to be correct for Vin+/-
    [ComboSensorBreakout.brd]
2020-09-28 Added initial dev for hard mounted sensor design
    Review and cleanup of layout required
    [HardMountSensor.brd, HardMountSensor.sch]
2020-09-28 Minor cleanup
    [HardMountSensor.brd]
2021-03-30 Preliminary board layout for Hedorah-NDIR
    Layout for interface board for NDIR (SCD30 Sensor) Hedorah
    [NDIR_SensorInterface.brd, NDIR_SensorInterface.sch]
2021-03-30 Fixed hole placement
    Adjusted the placement of the holes and cutout to fix errors
    [NDIR_SensorInterface.brd, NDIR_SensorInterface.dxf]
2024-08-12 Updated NDIR interface board to v1.0
    Added reverse polarity protection and I2C pull up resistors
    [NDIR_SensorInterface.brd, NDIR_SensorInterface.sch]
2024-08-12 Moved files into new folder structure
    [ComboSensorBreakout.brd, ComboSensorBreakout.sch, HardMountSensor.brd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]
2024-08-12 Added mechanical parts
    [HEDORAH-001_-_BetaBody_v000.SLDPRT, HEDORAH-001_-_BetaBody_v000.STL, HEDORAH-001_-_BetaBody_v001.SLDPRT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]
2024-08-27 Rearranged folders for version separation, software, production
    Added clear separation in hardware and production, dividing the files by version. Also moved demo code into software folder
    [NDIR_SensorInterface.dxf]
2024-08-27 Updated/generated BoMs if not present
    [ComboSensorBreakout.brd, ComboSensorBreakout.sch, ComboSensorBreakout_BoM_0v0.csv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]
2024-09-26 Mrk 3 prelim board design
    Added design for Mrk 3 sensor version
    [NDIR_SensorInterface.brd, NDIR_SensorInterface.sch, VertMount.brd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]
2024-09-26 Added mechanical design for Mrk 3 sensor enclosure
    [7513K142_PG-9 304 Stainless Steel Locknut for Metal Medium- and Thick-Wall Steel Conduit.SLDPRT, HEDORAH-004_-_VertLid_v000.SLDPRT, HEDORAH-004_-_VertLid_v000.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]
2024-09-26 Fixed production version naming of Mrk 2 design
    Added layout dimensions
    [NDIR_SensorInterface.brd, NDIR_SensorInterface.sch]
2024-11-02 Added graphics and mechanical parts
    [HEDORAH-003_-_BetaGasket_v001.SLDPRT]
